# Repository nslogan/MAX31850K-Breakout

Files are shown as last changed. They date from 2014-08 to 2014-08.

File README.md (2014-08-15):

# MAX31850K-Breakout

## Description

A small breakout board for the Maxim MAX31850K 1-wire type-K thermocouple amplifier with CJC. Project [available on GitHub](https://github.com/nslogan/MAX31850K-Breakout").

## Production

The board measures 0.85x0.85in (21.62x21.62mm) and is designed for production at [OSH Park](https://www.oshpark.com/). The OSHPark DRU is located in the `res/` folder.

The boards can be purchased [here](https://oshpark.com/shared_projects/TtoEusV0) @ $3.60 for three.

## Parts

All parts on this board are from the [LoganSmith-Eagle-Library](https://github.com/nslogan/LoganSmith-Eagle-Library) available on GitHub (work in progress).

The BOM is located in the `release/` folder, all parts are sourced from Digi-Key.

## Project Structure

This project adheres to this structure:

	[ProjectName]
		README.md
		[release]
			[Major.Minor]
				ProjectName_BOM_Major.Minor.xls or ProjectName_BOM_BOM_Major.Minor.csv
				ProjectName_schematic_Major.Minor.pdf
				ProjectName_board-<top/mid#/bottom>_Major.Minor.png
				ProjectName_Major.Minor.sch
				ProjectName_Major.Minor.brd
				[Gerbers]
					...
			...
		[src]
			[Major.0]
				BoardName.sch
				BoardName.brd
				BOM.xls or BOM.csv
			[Major+1.0]
				...
			...
		[lib]
			...
		[res]
			Manufacturer.dru
			Manufacturer.cam

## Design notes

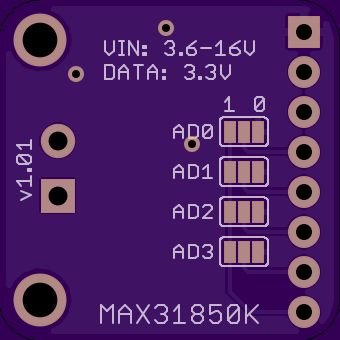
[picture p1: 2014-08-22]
release/1.01/MAX31850K-Breakout_board-bottom_1.01.png

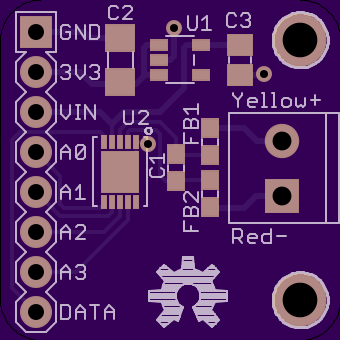
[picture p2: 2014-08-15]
release/1.0/MAX31850K-Breakout_board-bottom_1.0.png

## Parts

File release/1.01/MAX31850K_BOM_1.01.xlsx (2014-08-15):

Part | Qty | Package | Description | DIGIKEY_OC | MFR | MPN | TEMP_RANGE | Thick | Value
C1 | 1 | 0603-CAP | 0.1uF CER CAP X7R +/-10% | 1276-1005-1-ND | Samsung Electro-Mechanics America, Inc | CL10B104KO8NNNC | -55C to 125C | 0.90mm | 0.1uF
C2 | 1 | 1206-CAP | 10uF CER CAP X7R +/-10% | 1276-3103-1-ND | Samsung Electro-Mechanics America, Inc | CL31B106KLHNNNE | -55C to 125C | 1.80mm | 10uF
C3 | 1 | 0805-CAP | 10uF CER CAP X7R +/-10% | 1276-1113-1-ND | Samsung Electro-Mechanics America, Inc | CL21B106KQQNNNE | -55C to 125C | 1.40mm | 10uF
FB1,FB2 | 2 | 0603-RES | 1k@100MHz ferrite bead | 1276-6378-1-ND | Samsung Electro-Mechanics America, Inc. | CIM10J102NC |  | 0.95mm | 1kOhm@100MHz
J1 | 1 | 1X08_SQ1 | 1x8 Headers Gold 30uin | 609-3273-ND | FCI | 68001-108HLF |  | 0.230in | 1x8
J2 | 1 | SCREWTERMINAL-3.5MM-2 | 2 pos 3.5mm screw terminal 7A 250V 18-26 AWG | A98036-ND | TE Connectivity | 1776275-2 | -55C to 105C |  | 7A 250V
U1 | 1 | SOT23-5 | Fixed output Texas Instruments LDO | 296-18476-1-ND | Texas Instruments | LP2985-33DBVR | -40C to 125C |  | 3.3V
U2 | 1 | 10-TDFN-EP | Cold-Junction Compensated, 1-Wire Thermocouple-to-Digital Converters | MAX31850KATB+-ND | Maxim Integrated | MAX31850KATB+ | -40C to 125C |  | Type K

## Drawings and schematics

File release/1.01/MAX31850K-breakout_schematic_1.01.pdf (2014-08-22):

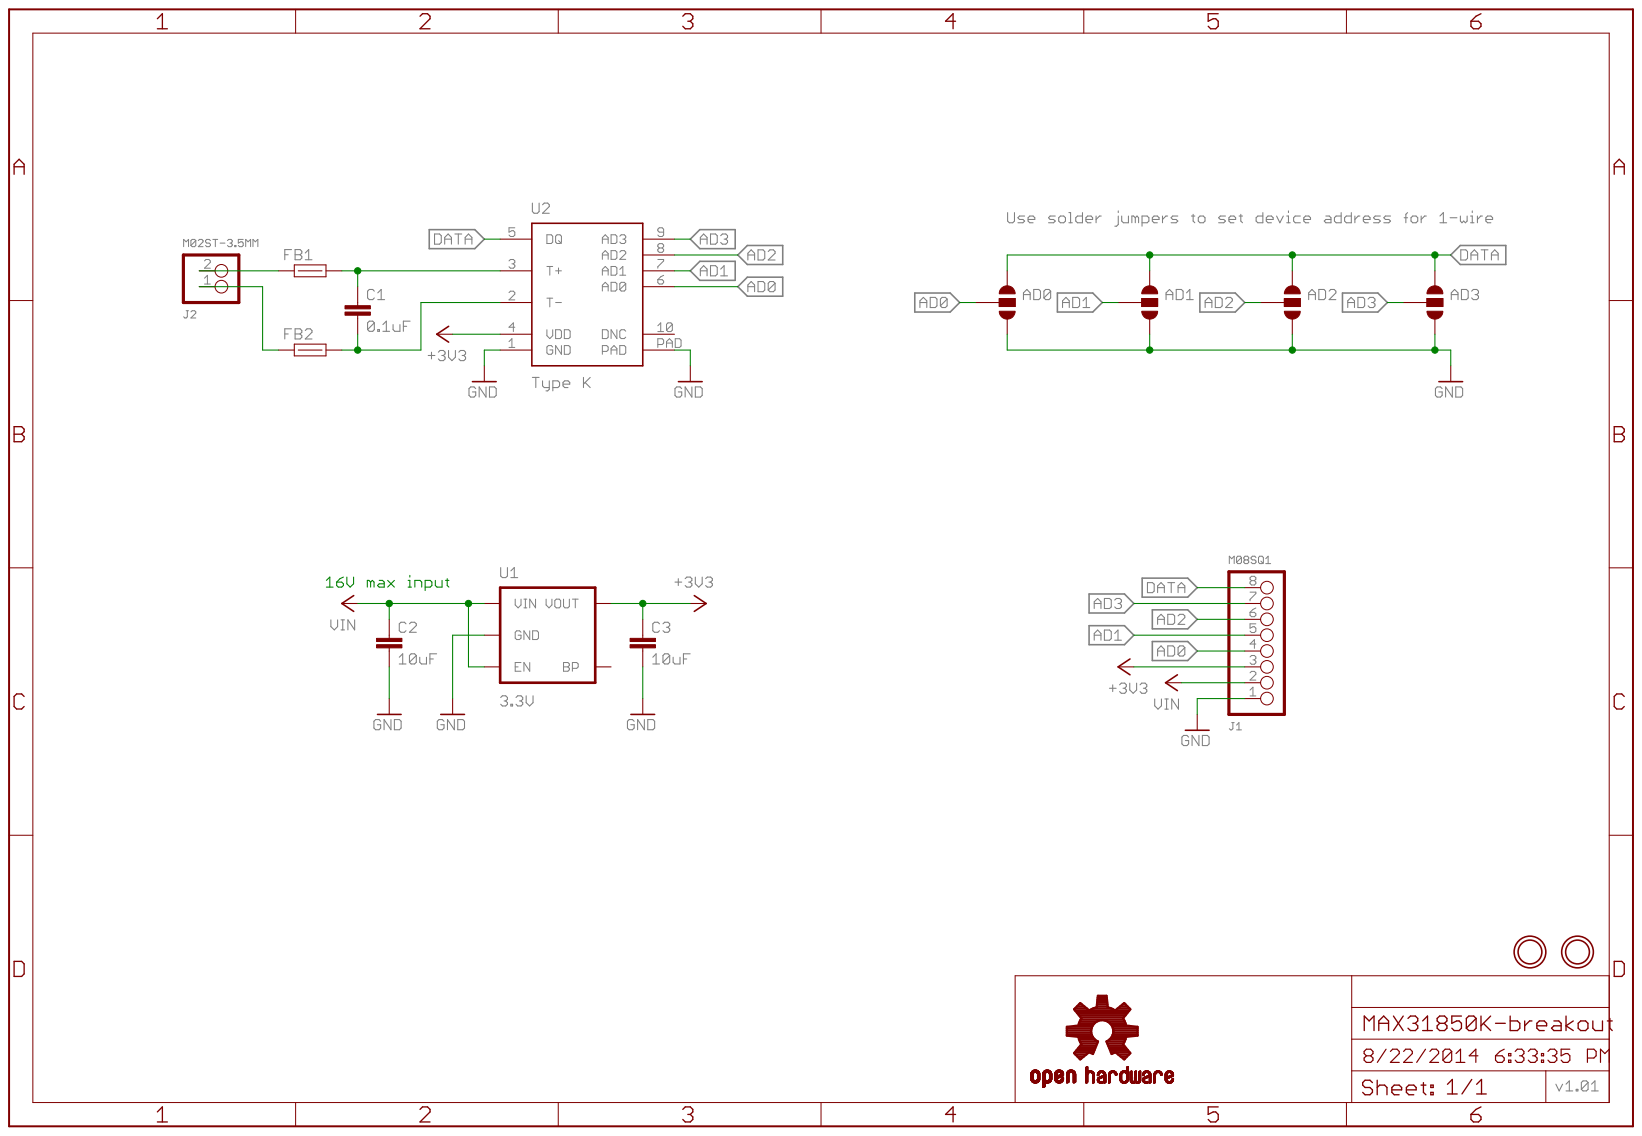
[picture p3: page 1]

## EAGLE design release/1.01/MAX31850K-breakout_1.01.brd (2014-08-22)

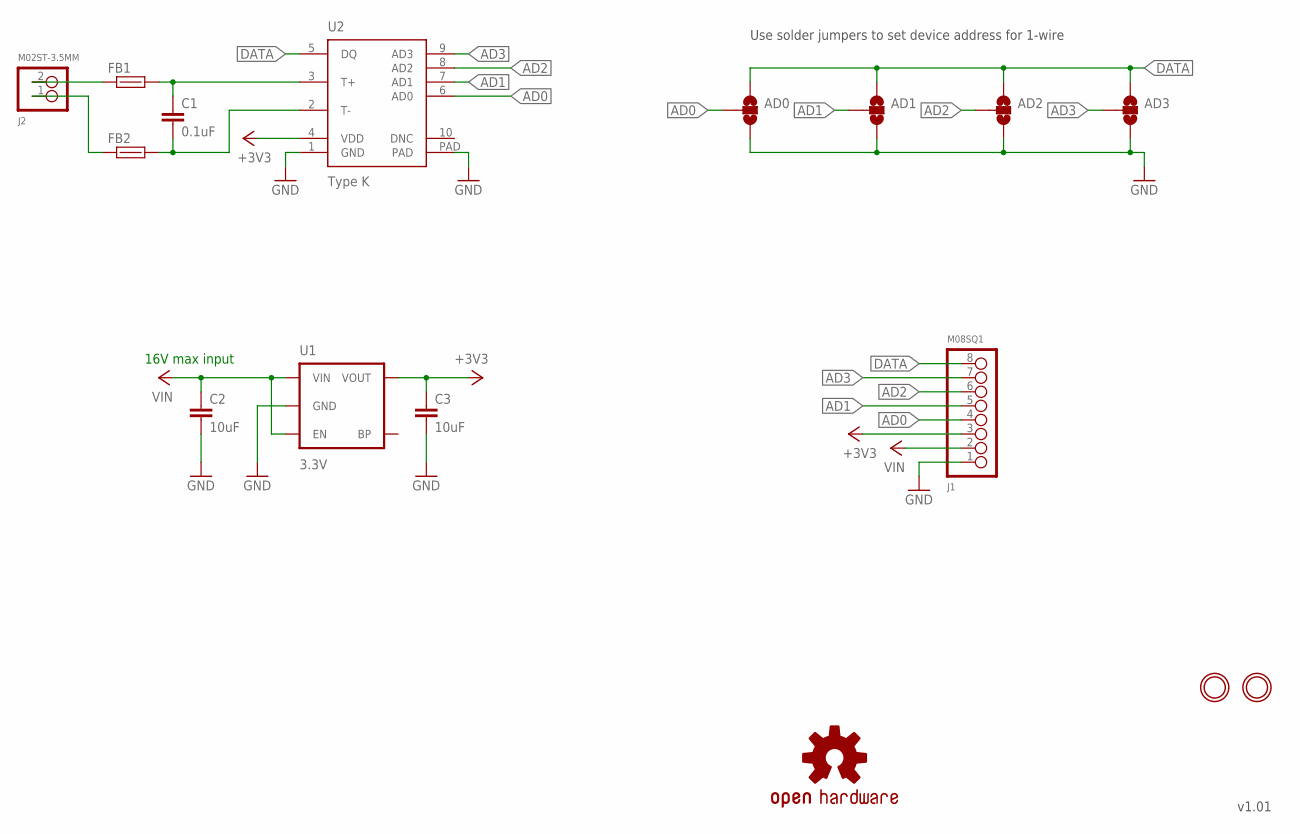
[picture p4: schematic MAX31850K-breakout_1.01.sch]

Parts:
AD0, AD1, AD2, AD3: SJ_2WAYS; SJ_3
C1: 0.1uF; 0603-CAP
C2: 10uF; 1206-CAP
C3: 10uF; 0805-CAP
FB1, FB2: FB-1K-100MHZ-0603; 0603-RES
J1: M08SQ1; 1X08_SQ1
J2: M02ST-3.5MM; SCREWTERMINAL-3.5MM-2
LOGO1: OSHW-LOGOM; OSHW-LOGO-M
U1: 3.3V; SOT23-5
U2: Type K; 10-TDFN-EP
U$1, U$2: MNTHOLE-2.0; MOUNTINGHOLE_2.0_PLATED

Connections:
+3V3: C3.P$1 (1), J1.3, U1.5 (VOUT), U2.4 (VDD)
AD0: AD0.2, J1.4, U2.6 (AD0)
AD1: AD1.2, J1.5, U2.7 (AD1)
AD2: AD2.2, J1.6, U2.8 (AD2)
AD3: AD3.2, J1.7, U2.9 (AD3)
DATA: AD0.1, AD1.1, AD2.1, AD3.1, J1.8, U2.5 (DQ)
GND: AD0.3, AD1.3, AD2.3, AD3.3, C2.P$4 (2), C3.P$2 (2), J1.1, U1.2 (GND), U2.1 (GND), U2.PAD
TM_FILT: C1.P$2 (2), FB2.P$2 (2), U2.2 (T-)
TM_RAW: FB2.P$1 (1), J2.1
TP_FILT: C1.P$1 (1), FB1.P$2 (2), U2.3 (T+)
TP_RAW: FB1.P$1 (1), J2.2
VIN: C2.P$3 (1), J1.2, U1.1 (VIN), U1.3 (EN)

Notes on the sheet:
16V max input
Use solder jumpers to set device address for 1-wire

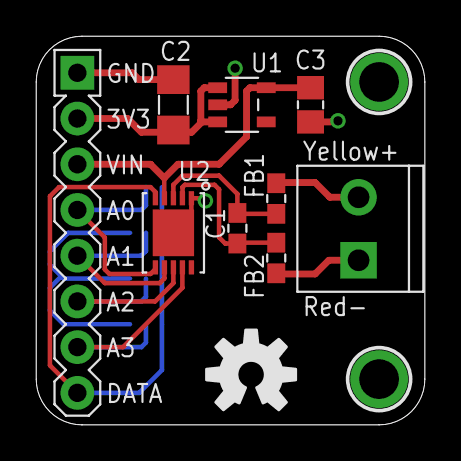
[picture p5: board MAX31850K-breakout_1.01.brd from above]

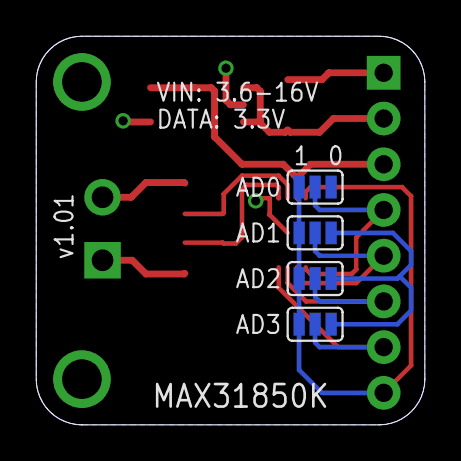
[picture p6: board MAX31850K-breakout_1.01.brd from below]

Board: 2 copper layers, 21.6 x 21.6 mm, 16 parts (4 on the bottom side), 12 nets.

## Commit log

2014-07-28 Added schematic and board.
    [MAX31850K_breakout.brd, MAX31850K_breakout.sch]
2014-07-30 Almost have all components created in LoganSmith-Eagle-Library.
    [MAX31850K_breakout.brd, MAX31850K_breakout.sch]
2014-08-01 Updated file structure to match PCBGuidelines structure (still in development). Preparing to move to release candidate.
    [MAX31850K_breakout.brd, MAX31850K_breakout.sch]
2014-08-01 Slighly rearranged silk.
    [MAX31850K_breakout.brd]
2014-08-01 Added BOM, still need part number for 1x8 header.
    [BOM.xlsx, MAX31850K_breakout.brd, MAX31850K_breakout.sch]
2014-08-02 Added 1x8 header to BOM.
    [BOM.xlsx]
2014-08-15 Create release folder, finalized BOM. Still need to make schematic PDF. Realized I need to make a hotfix 1.01 to correct board name - it's the MAX31850K, not the MAX31851K.
    [MAX31850K-breakout.brd, MAX31850K-breakout.sch, MAX31850K-breakout_1.0.brd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]
2014-08-15 Added PDF of schematic, pushing version 1.0.
2014-08-15 Fixed the MAX31851K to be MAX31850K on the bottom silk.
    [MAX31850K-breakout.brd]
2014-08-15 Added 1.01 files.
    [MAX31850K-breakout_1.01.brd, MAX31850K-breakout_1.01.sch, MAX31850K_BOM_1.01.xlsx]
2014-08-22 Forgot to up the version on the silk. Added version to schematic. Both use global attribute called CVERSION.
    [MAX31850K-breakout.brd, MAX31850K-breakout.sch, MAX31850K-breakout_1.01.brd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]

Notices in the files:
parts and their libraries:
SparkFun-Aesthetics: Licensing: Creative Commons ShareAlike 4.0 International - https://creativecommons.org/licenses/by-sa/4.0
